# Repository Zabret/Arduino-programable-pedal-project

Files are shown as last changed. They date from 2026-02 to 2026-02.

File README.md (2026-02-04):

<p align="center">
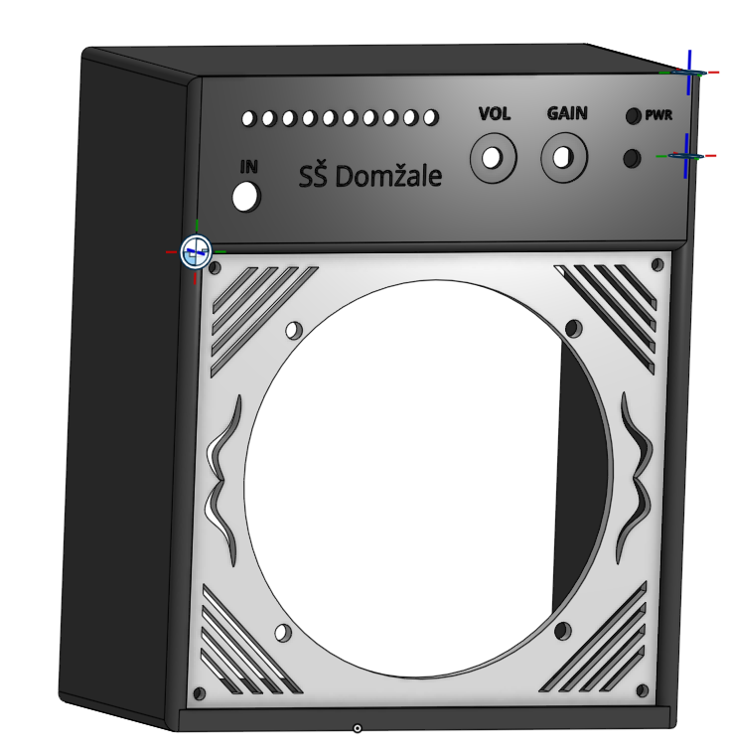
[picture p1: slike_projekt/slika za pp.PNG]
  
  &nbsp;&nbsp;&nbsp;&nbsp;
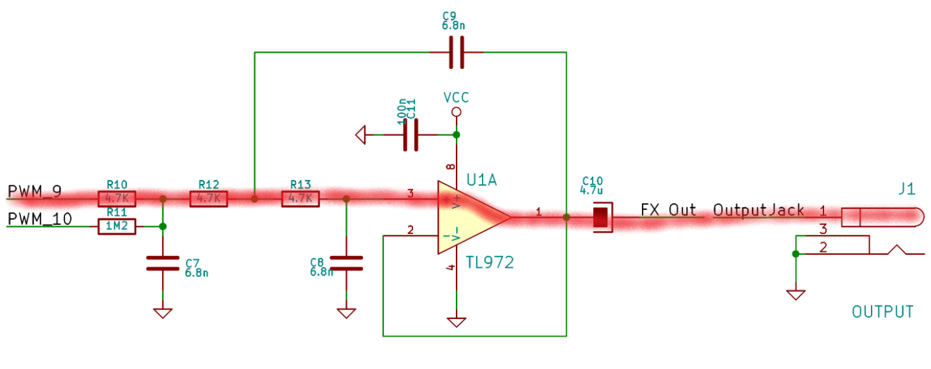
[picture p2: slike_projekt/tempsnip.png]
  
  &nbsp;&nbsp;&nbsp;&nbsp;
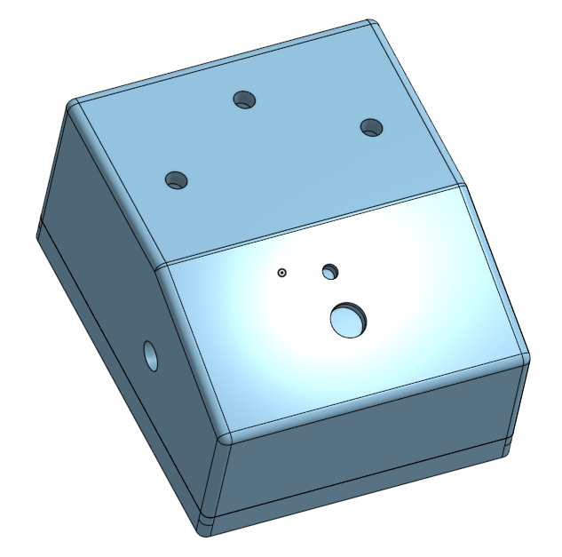
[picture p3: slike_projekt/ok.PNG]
  
</p>
<h1 align="center">Arduino-programable-pedal-project</h1>

A project insipred by Electrosmash arduino guitar pedal.
The report is about the construction process of an amplifier and a lo-fi programmable guitar pedal using an Arduino UNO microcontroller. The amplifier contains a 100W speaker powered by a 9V battery through a home-made printed circuit board. It also contains a VU-meter to monitor the sound signal strength. All components are built into the housing, which is made with the help of a 3D printer. The guitar pedal is also made from a homemade printed circuit board that amplifies the signal coming from the guitar and prepares it for the Arduino's analog-to-digital converter. The Arduino receives the digitized signal, processes it into the desired form of guitar effect (distortion, fuzz, bitcrusher,...) and sends it to the connected output unit or amplifier. The program that processes the signal is written in the C programming language.

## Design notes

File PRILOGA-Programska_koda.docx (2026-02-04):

# PRILOGA – programska koda

//Definiranje konstant in njihovih vhodnih pinov

#define LED 13

#define STOPALKA 12

#define STIKALO 2

#define GUMB_1 A5

#define GUMB_2 A4

//--------------------------------------------------------------------------------------------------------------------

//Nastavljanje pravilnih vrednosti izhodov PWM -Elecstrosmash(2017)

#define PWM_FREQ 0x00FF // Frekvenca 31,3kHz

#define PWM_MODE 0// Hitri način (1) ali način z fazno korekcijo (0)

#define PWM_QTY 2 // Nastavitev 2eh vzporednih izhodov

//--------------------------------------------------------------------------------------------------------------------

//Definiranje spremenljivk :

int input;

int stevec=0;

int efekt=0;

int pozicija=0;

byte ADC_low, ADC_high;

int glasnost=10000;

int max_f=6000;

int bitcrush=0;

//--------------------------------------------------------------------------------------------------------------------

void setup() {

// Določanje načina delovanja za vsako konstanto :

pinMode(STOPALKA, INPUT_PULLUP);

pinMode(STIKALO, INPUT_PULLUP);

pinMode(GUMB_1, INPUT_PULLUP);

pinMode(GUMB_2, INPUT_PULLUP);

pinMode(LED, OUTPUT);

//--------------------------------------------------------------------------------------------------------------------

// Nastavitev ADC (Analogno digitalnega pretvornika)-Elecstrosmash(2017)

ADMUX = 0x60;

ADCSRA = 0xe5;

ADCSRB = 0x07;

DIDR0 = 0x01;

//--------------------------------------------------------------------------------------------------------------------

// Nastavitev PWM (Pulzno širinske modulacije signalov):

TCCR1A = (((PWM_QTY - 1) << 5) | 0x80 | (PWM_MODE << 1));

TCCR1B = ((PWM_MODE << 3) | 0x11);

TIMSK1 = 0x20;

ICR1H = (PWM_FREQ >> 8);

ICR1L = (PWM_FREQ & 0xff);

DDRB |= ((PWM_QTY << 1) | 0x02);

//--------------------------------------------------------------------------------------------------------------------

//Razbere pozicijo stikala:

pozicija = digitalRead(STIKALO);

}

//--------------------------------------------------------------------------------------------------------------------

void loop() // ta del programa se vedno izvaja.

{

//Če je pedalo prižgano se prižge LED luč.

if (digitalRead(STOPALKA)) digitalWrite(LED, HIGH);

else digitalWrite(LED, LOW);

// Glede na pozicijo stikala se efekt spremeni.

if(digitalRead(STIKALO)!=pozicija)

{

pozicija = digitalRead(STIKALO); //Posodobi na novo vrednost.

efekt++;

if (efekt>3) efekt=0; //Če je efekt nastavljen na več kot vrednost 3, se nastavi na 0.

//Privzete vrednosti efektov:

glasnost=10000;

max_f=6000;

bitcrush=0;

}

}

//--------------------------------------------------------------------------------------------------------------------

ISR(TIMER1_CAPT_vect) {

// tukaj dobimo podatke iz ADC-ja

ADC_low = ADCL; // zapiše nižjo polovico bitov

ADC_high = ADCH; // zapiše višjo polovico bitov

input = ((ADC_high << 8) | ADC_low) + 0x8000; // ustvari podpisano 16 bitno število

//posodobi

stevec++;

if(stevec==100)

{

stevec=0;

//--------------------------------------------------------------------------------------------------------------------

//Če pritisnemo GUMB_2 se vrednosti izbranega efekta povečajo:

if (!digitalRead(GUMB_2)) {

if (glasnost<32768)glasnost=glasnost+10; //poveča glasnost

if (max_f<32768)max_f=max_f+25; //poveča fuzz

if (bitcrush<16)bitcrush=bitcrush+1; //poveča bitcrusher

digitalWrite(LED, LOW); //požmiga LED

}

//Če pritisnemo GUMB_1 se vrednosti izbranega efekta zmanjšajo:

if (!digitalRead(GUMB_1)) {

if (glasnost>0)glasnost=glasnost-10; //zmanjša glasnost

if (max_f>0)max_f=max_f-25; //zmanjša fuzz

if (bitcrush>0)bitcrush=bitcrush-1; //zmanjša bitcrusher

digitalWrite(LED, LOW); //požmiga LED

}

}

//--------------------------------------------------------------------------------------------------------------------

if (efekt==0)

{

//brez efekta.

}

else if(efekt==1) //glasnost

{

input = map(input, -32768, +32768,-glasnost, glasnost);

}

else if(efekt==2) //fuzz

{

if(input>max_f) input=32768;

else if(input<-max_f) input=-32768;

}

else if(efekt==3) //Bitcrusher

{

input = input<<bitcrush;

}

//izpiše PWM signal

OCR1AL = ((input + 0x8000) >> 8); // prevede nazaj v nadpisano število brez dvojiškega komplimenta

OCR1BL = input; // pošlje še nižji bit

}

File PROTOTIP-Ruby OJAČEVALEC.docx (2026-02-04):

# PROTOTIP – Ruby ojačevalec

## Kaj je Ruby ojačevalec ?

Je ojačevalec ki temelji na integriranem vezju LM386, ki ga je zasnoval Runoffgroove. Njegova naloga je ojačati signal ki pride iz kitare in ga predvajati skozi zvočnike.

## Osnutek načrta izdelave izdelka

Za izdelavo Ruby ojačevalca bi se zgledoval po sledeči shemi:

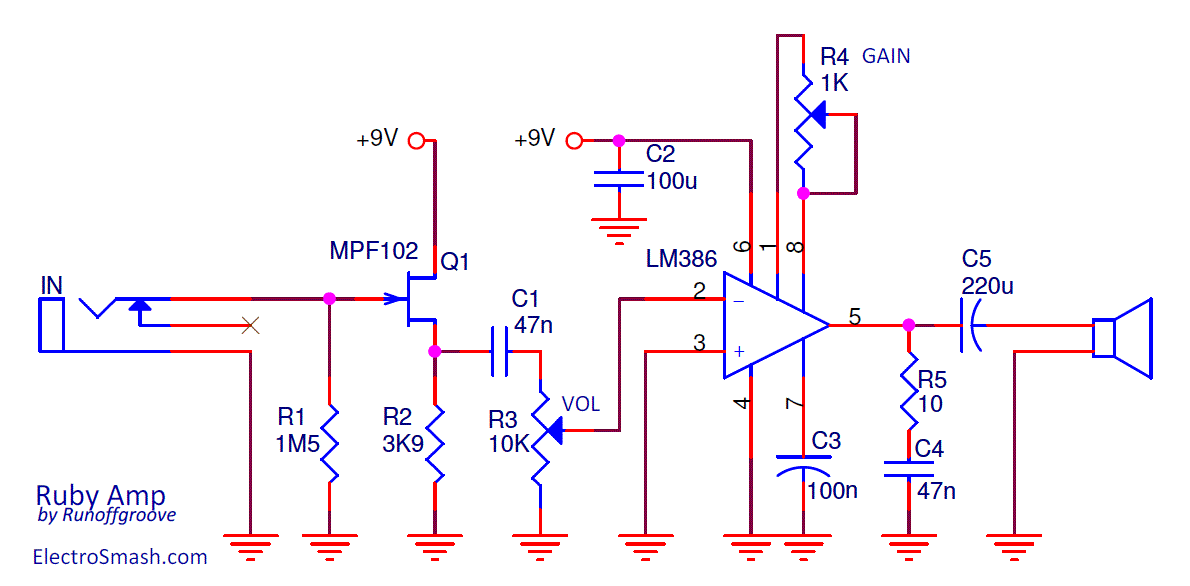
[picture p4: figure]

1W

Ojačevalec bi bil vezan na preprost 1W zvočnik, ki bi popolnoma zadoščal potrebam po glasnosti in kvaliteti. Navdih za ojačevalec sem dobil od izdelka na povezavi :
https://www.instructables.com/Portable-Ruby-Amp/

Ohišje ojačevalca bi ustvaril iz lesa in pomočjo domačega 3D-tiskalnika.

## Spisek komponent – Ruby ojačevalec

Reference | Št. kosov | Vrednosti | Opis
Kondenzatorji
C1, C4 | 2 | 47n
C2 | 1 | 100uf | electrolytic cap
C5 | 1 | 220uf | electrolytic cap
C3 | 1 | 100n
Uporniki
R5 | 1 | 10Ω
R2 | 1 | 3.9kΩ
R1 | 1 | 1.5MΩ
R6 | 1 | 4.7kΩ
R4 | 1 | 1kΩ
R3 | 1 | 10kΩ
Ostalo
MPF102 Tranzistor | 1
Potenciometer | 1 | 10KΩ
Potenciometer | 1 | 1KΩ
Stereo 6.35mm priključek | 1 | | ¼ stereo jack
9V priključek za baterijo | 1 | 9V
Baterija | 1 | 9V
Stikalo | 1 | | SPDT toogle switch
LED | 1 | 5mm
Prazna bakrena pcb ploščica -FR4 | 1 | | 100mm*70mm
zvočnik | 1 | 1W
LM386IC | 1

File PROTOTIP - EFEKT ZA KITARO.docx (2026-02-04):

# PROTOTIP – KITARSKI EFEKT

## Kaj so kitarski efekti?

Kitarski efekti so elektronske naprave, ki spreminjajo ton, njegovo višino, ali zvok električne kitare. Poleg električne kitare so te efekti vgrajeni tudi v električnih klavirjih in bass kitarah.

## Osnutek načrta izdelave izdelka

Za izdelavo kitarskega efekta bi se zgledoval po shemi pedalshieldUNO (https://www.electrosmash.com/pedalshield-uno) avtorja electroSmash, ki temelji na implementaciji arduino-UNO mikrokontrolerja skupaj s posebnim tiskanim vezjem ki omogoča prenos in alteracijo signala električne kitare skozi arduino do ojačevalca.

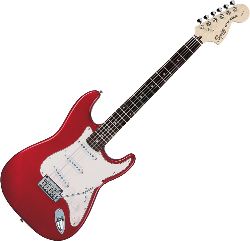
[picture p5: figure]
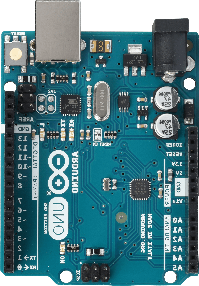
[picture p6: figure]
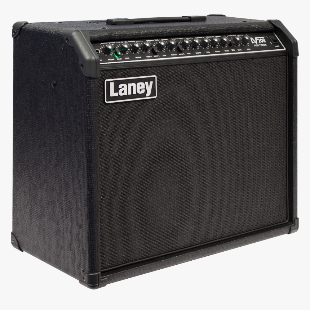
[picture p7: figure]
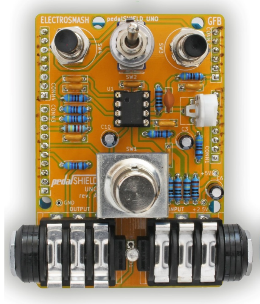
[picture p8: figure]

signal

signal

vmesnik

arduino

Glavna komponenta izdelka bo vmesnik, ki bo omogočal arduinu dostop do signala kitare, hkrati pa vseboval tudi stikala za sam efekt.

Vmesnik bi zgradil na tiskanem vezju katerega bi ustvaril s pomočjo jedkanja ali laserskega graviranja bakrene ploščice namenjene gradnji vezij, na katero bi potem za spajkal potrebne elemente.
Ohišje efekta bi natančno narisal v CAD programu in ustvaril s pomočjo domačega 3-D tiskalnika.

Zadnji korak pri izdelavi izdelka je sama koda, ki bi omogočala pretvorbo oziroma spremembo signala za zaželen efekt. Program bi napisal v programskem jeziku C++, po zgledu Electrosmash zbirke digitalnih efektov.

Pri izdelavi vezja bi se zgledoval po sledeči shemi :

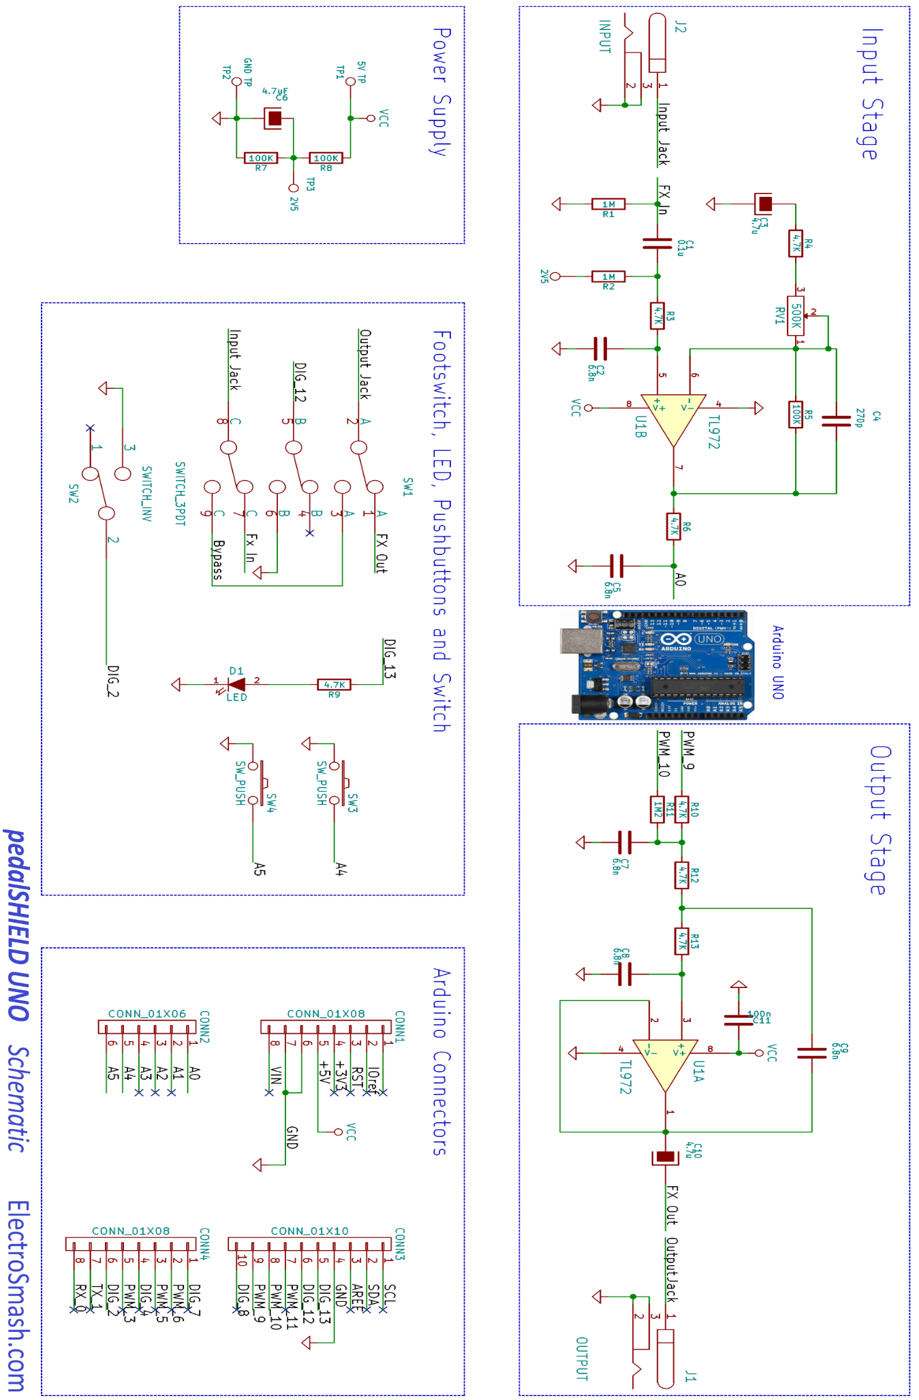
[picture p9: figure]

## Spisek komponent -efekt

Reference | Št. kosov | Vrednosti | Opis | Mauser reference
Kondenzatorji
C5,C2, C7, C8, C9 | 5 | 6.8n | ceramic cap | SR211C682MARTR1
C3, C6, C10 | 3 | 4.7u | electrolytic cap | ECE-A1EKA4R7
C1, C11 | 2 | 100n | ceramic cap | SR211C104KARTR1
C4 | 1 | 270p | ceramic cap | D271K20Y5PH63L6R

Uporniki
R12,R13, R10, R9, R6, R4, R3 | 7 | 4.7K | Resistor, 1%,1/4W | MFR-25FRF52-4K7
R5, R7, R8, | 3 | 100K | Resistor, 1%,1/4W | MFR-25FRF52-100K
R1, R2 | 2 | 1M | Resistor, 1%,1/4W | MFR-25FRF52-1M
R11 | 1 | 1M2 | Resistor, 1%,1/4W | MFR-25FRF52-1M2

Ostalo
RV1 | 1 | 500K | resistor trimmer | 3319W-1-504
D1 | 1 | Led 3mm blue | blue led 3mm | SSL-LX3044USBC
U1 | 1 | TL972 pdip-8 | op-amp rail-to-rail | 595-TL972IP
IC Socket | 1 | dip 8 socket | socket dor dip8 | 1-2199298-2
SW1 | 1 | 3DPT footswitch | 3PDT footswitch | 107-SF17020F-32-21RL
SW2 | 1 | Toggle switch | SPDT toogle switch | 612-100-A1111
SW3, SW4 | 2 | Pushbutton | off-on pushbutton | 103-1013-EVX
Conn1,2,3,4 | 1 | 40 pin headers | 2.54 pitch pin header | 710-61304011121
J1, J2 | 2 | 1/4 Jack audio | stereo 6.35mm jack | NMJ6HCD2
Prazna bakrena pcb ploščica -FR4 | 1

*Bakreno pcb ploščico bi po potrebi lahko zamenjal tudi z protoboardom.

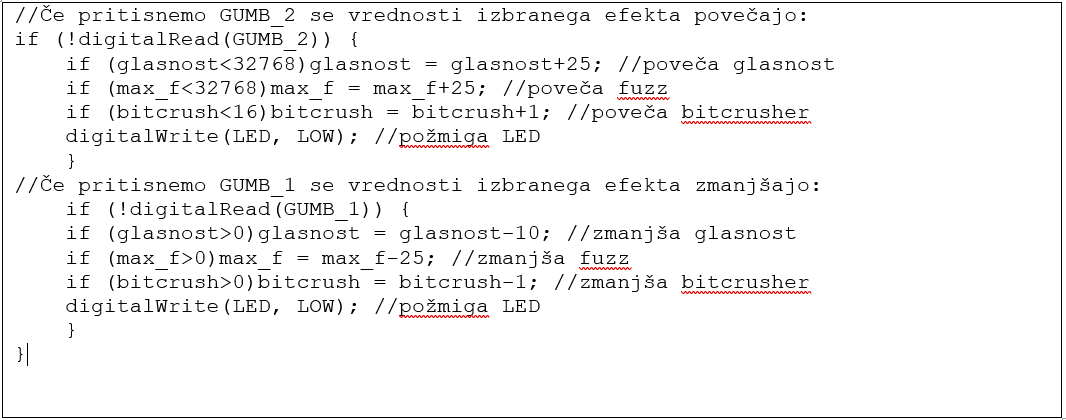
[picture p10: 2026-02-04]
slike_projekt/p.PNG

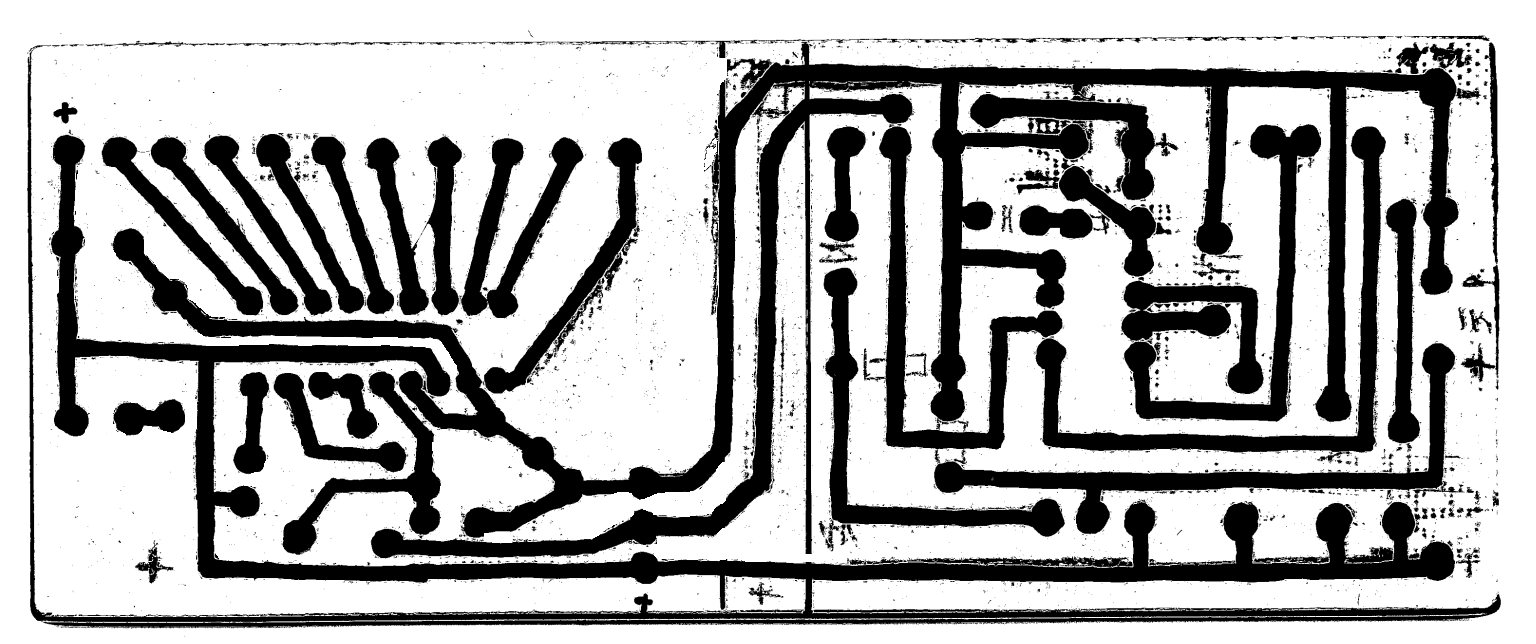
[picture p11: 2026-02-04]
slike sheme/shema ojacevalec.PNG

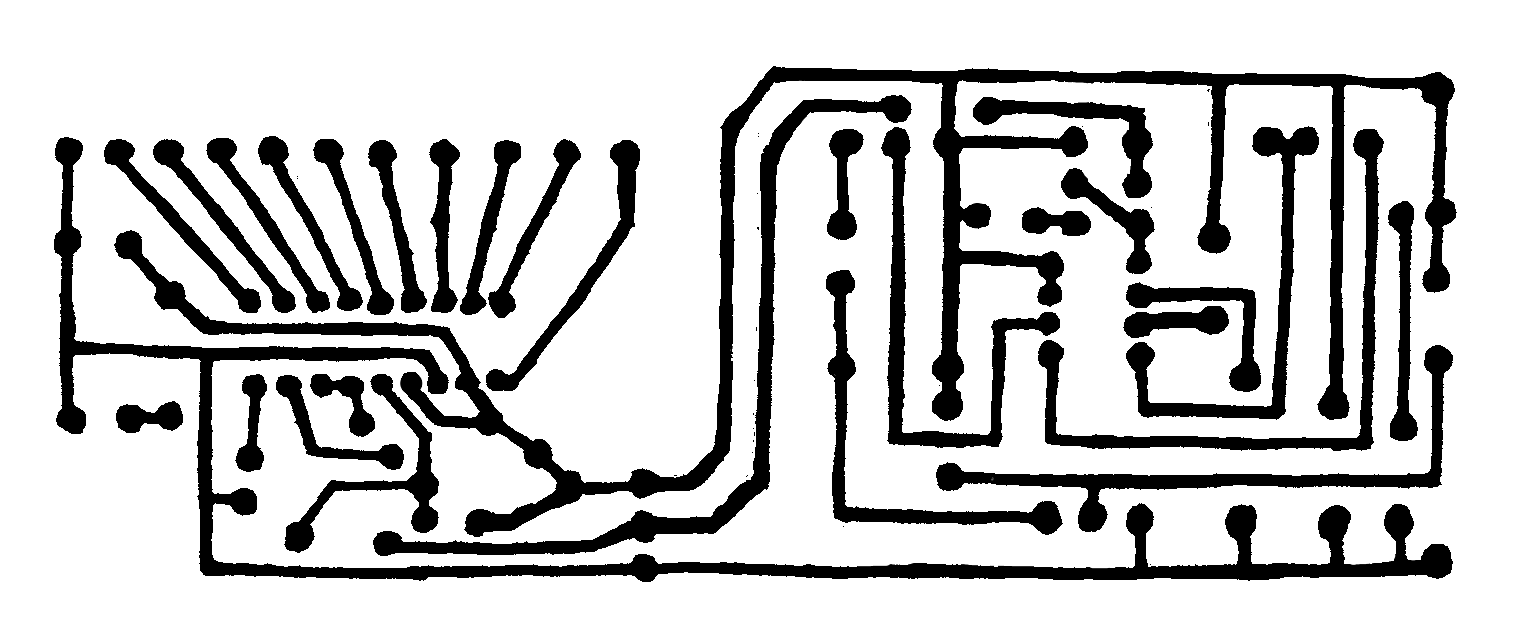
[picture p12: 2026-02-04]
slike sheme/shema ojacevalec pt2.png

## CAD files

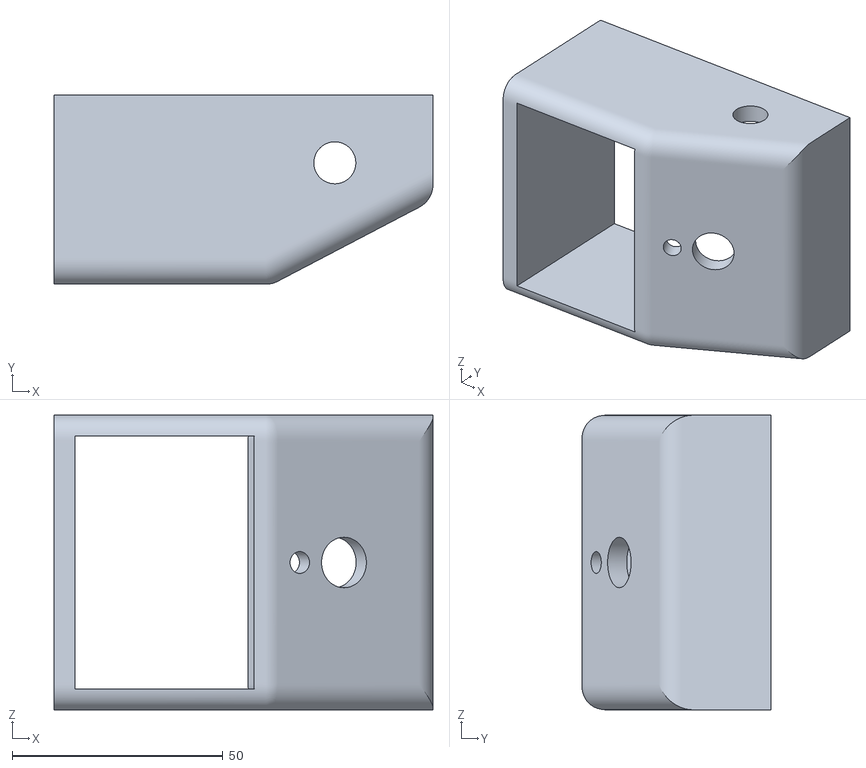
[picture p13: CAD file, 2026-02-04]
3D_datotekeGCODE/okvir_za_pedal.stl
90.0 x 45.0 x 70.0

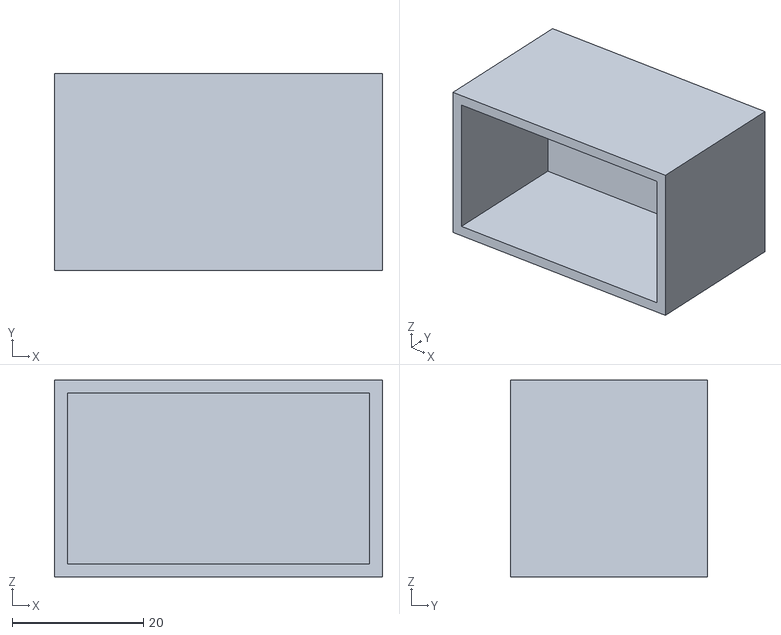
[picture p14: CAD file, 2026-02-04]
3D_datotekeGCODE/skatlica.stl
50.0 x 30.0 x 30.0

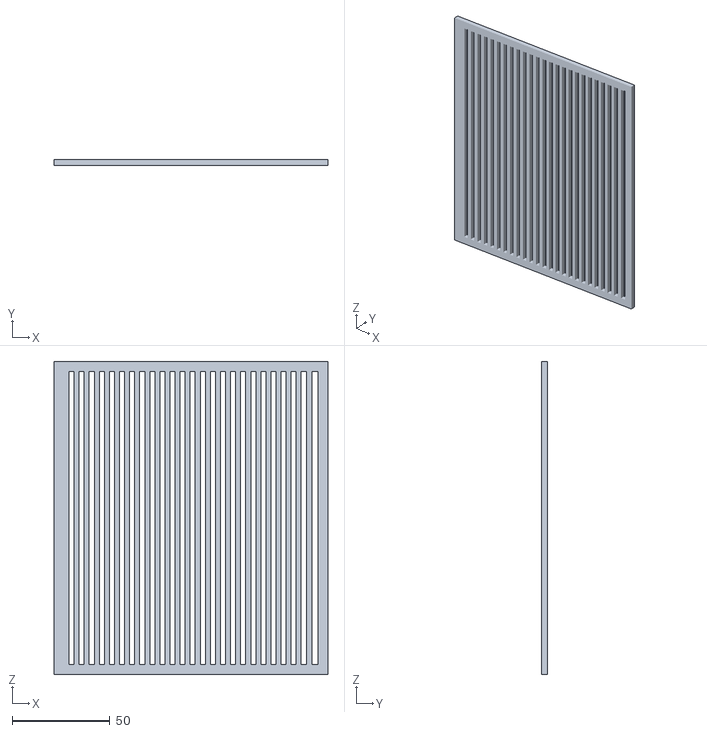
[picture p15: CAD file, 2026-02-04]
3D_datotekeGCODE/resetka1.stl
140.0 x 3.00 x 160.2

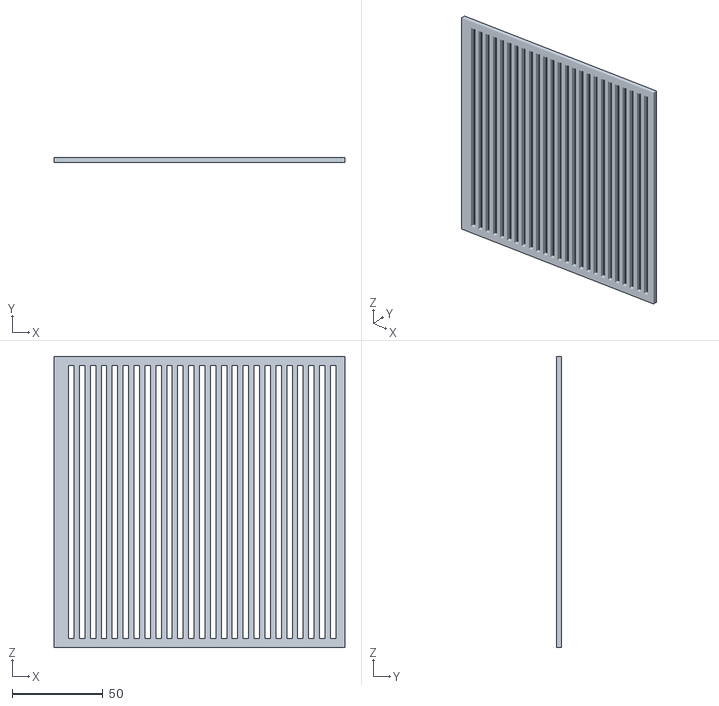
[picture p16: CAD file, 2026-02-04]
3D_datotekeGCODE/resetka.stl
160.0 x 3.00 x 160.2

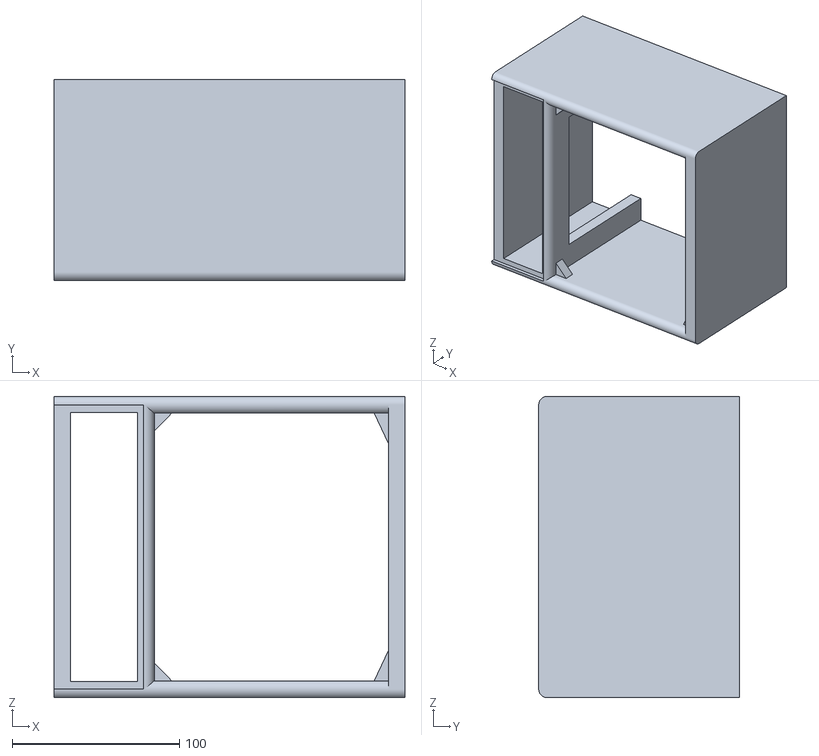
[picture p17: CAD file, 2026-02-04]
3D_datotekeGCODE/ohisje_ojacevalca1.stl
210.0 x 120.0 x 180.2

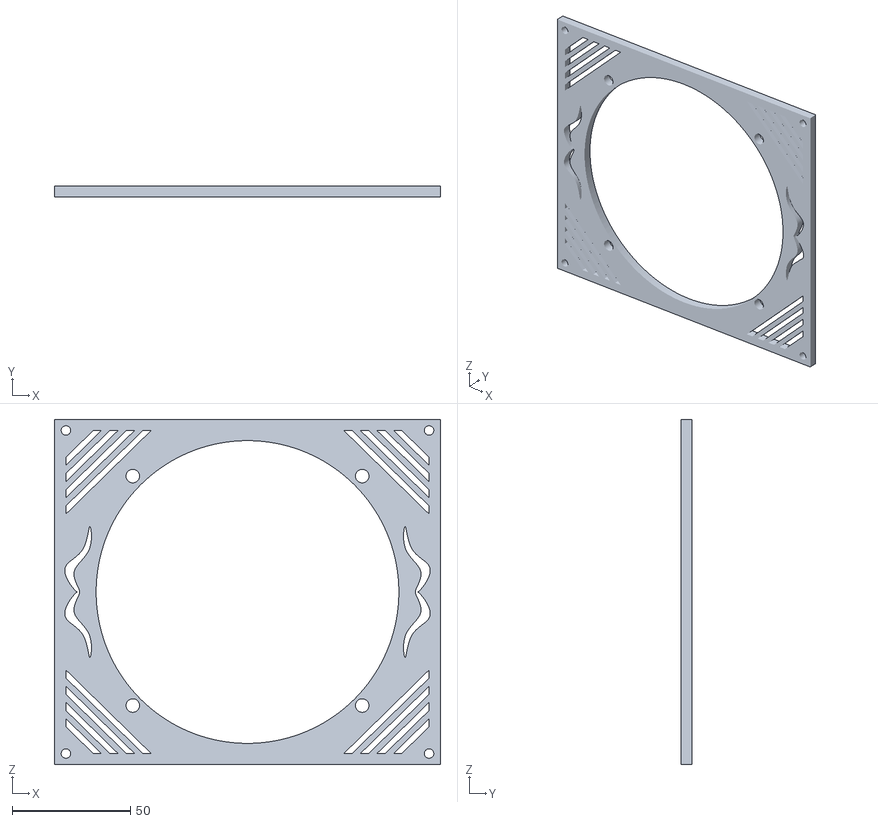
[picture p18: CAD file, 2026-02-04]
3D_datotekeGCODE/posodoblena_resetka.stl
163.2 x 4.50 x 146.0

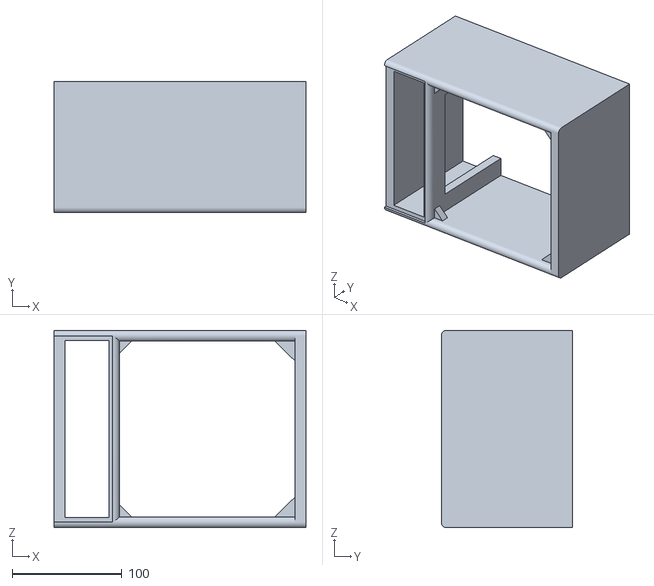
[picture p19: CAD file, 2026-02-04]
3D_datotekeGCODE/ohisje_ojacevalca.stl
230.0 x 120.0 x 180.2

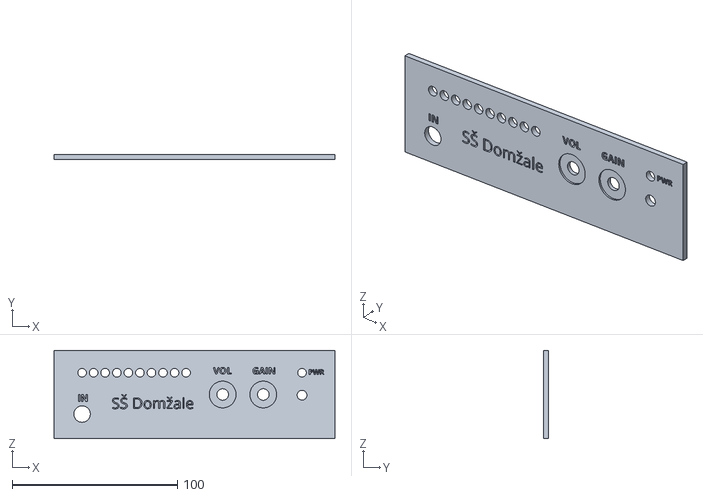
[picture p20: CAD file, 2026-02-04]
3D_datotekeGCODE/celna_plosca.stl
170.2 x 3.00 x 53.5

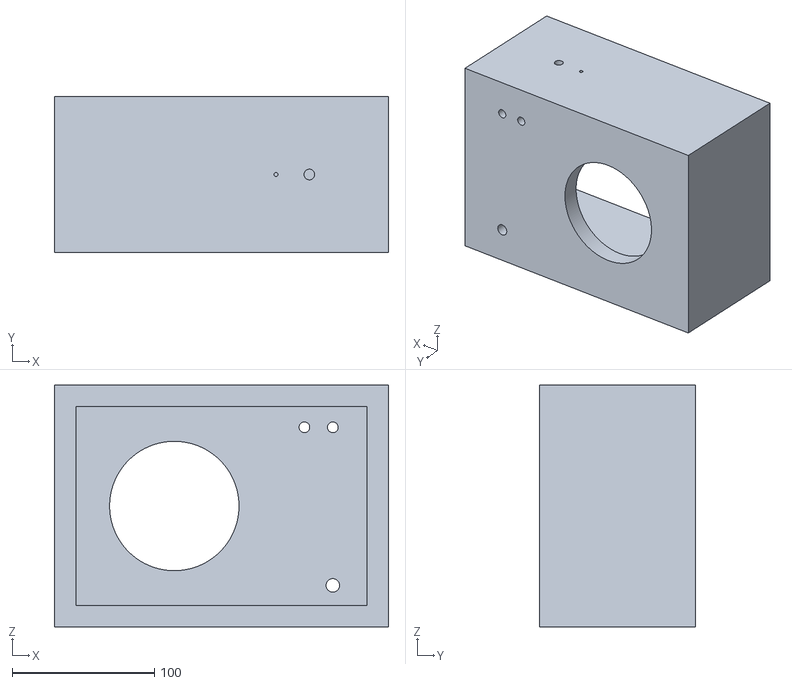
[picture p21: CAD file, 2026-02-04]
3D_datotekeGCODE/Ojačevalec.stl
235.0 x 110.0 x 170.0

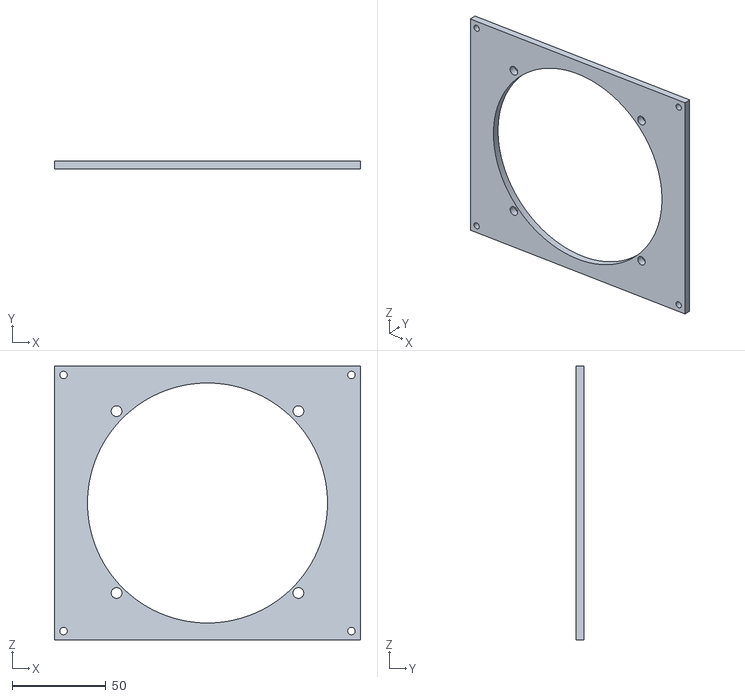
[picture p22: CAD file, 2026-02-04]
3D_datotekeGCODE/resetkanova.stl
163.2 x 4.50 x 146.0

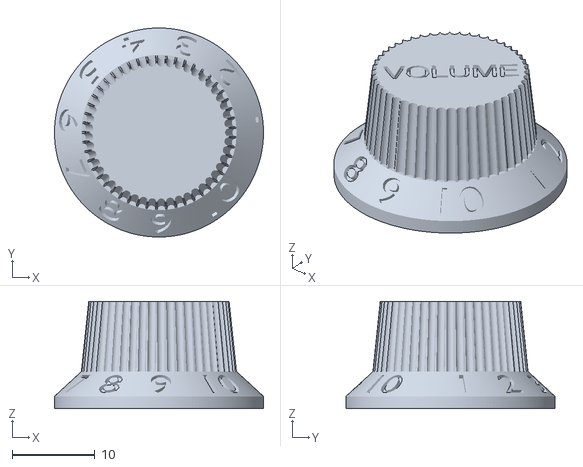
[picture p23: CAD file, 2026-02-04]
3D_datotekeGCODE/knob_right_volume.stl
25.3 x 25.3 x 13.0

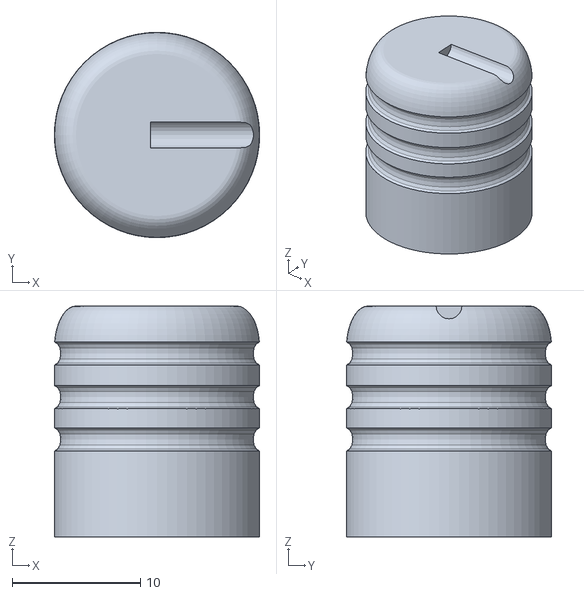
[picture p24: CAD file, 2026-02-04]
3D_datotekeGCODE/ring_Guitar_Amp_Knob.stl
16.0 x 16.0 x 18.0

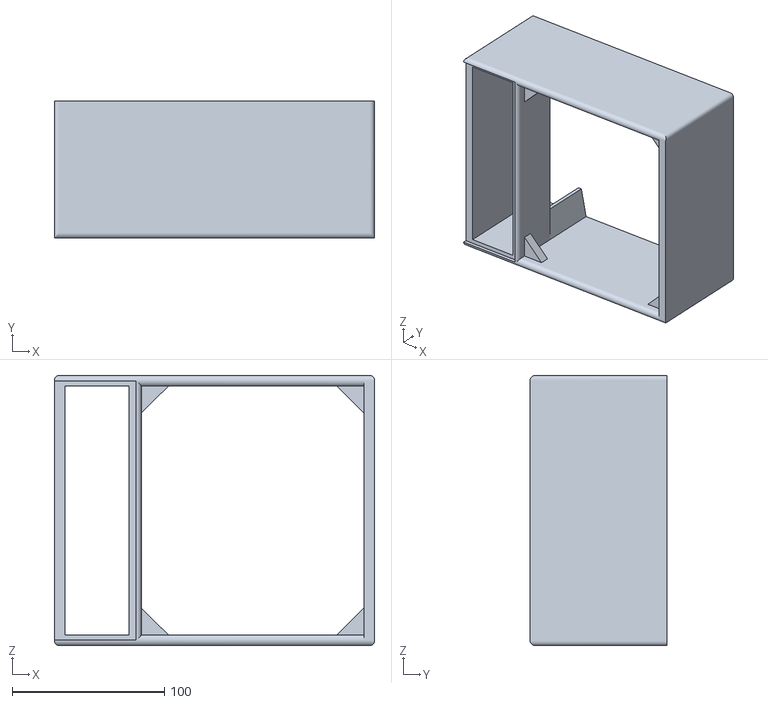
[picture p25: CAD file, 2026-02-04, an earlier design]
3D_datotekeGCODE/ohisje_ojacevalca (3).stl
210.0 x 90.0 x 177.2

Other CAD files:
3D_datotekeGCODE/Čelna_Plošča.stl

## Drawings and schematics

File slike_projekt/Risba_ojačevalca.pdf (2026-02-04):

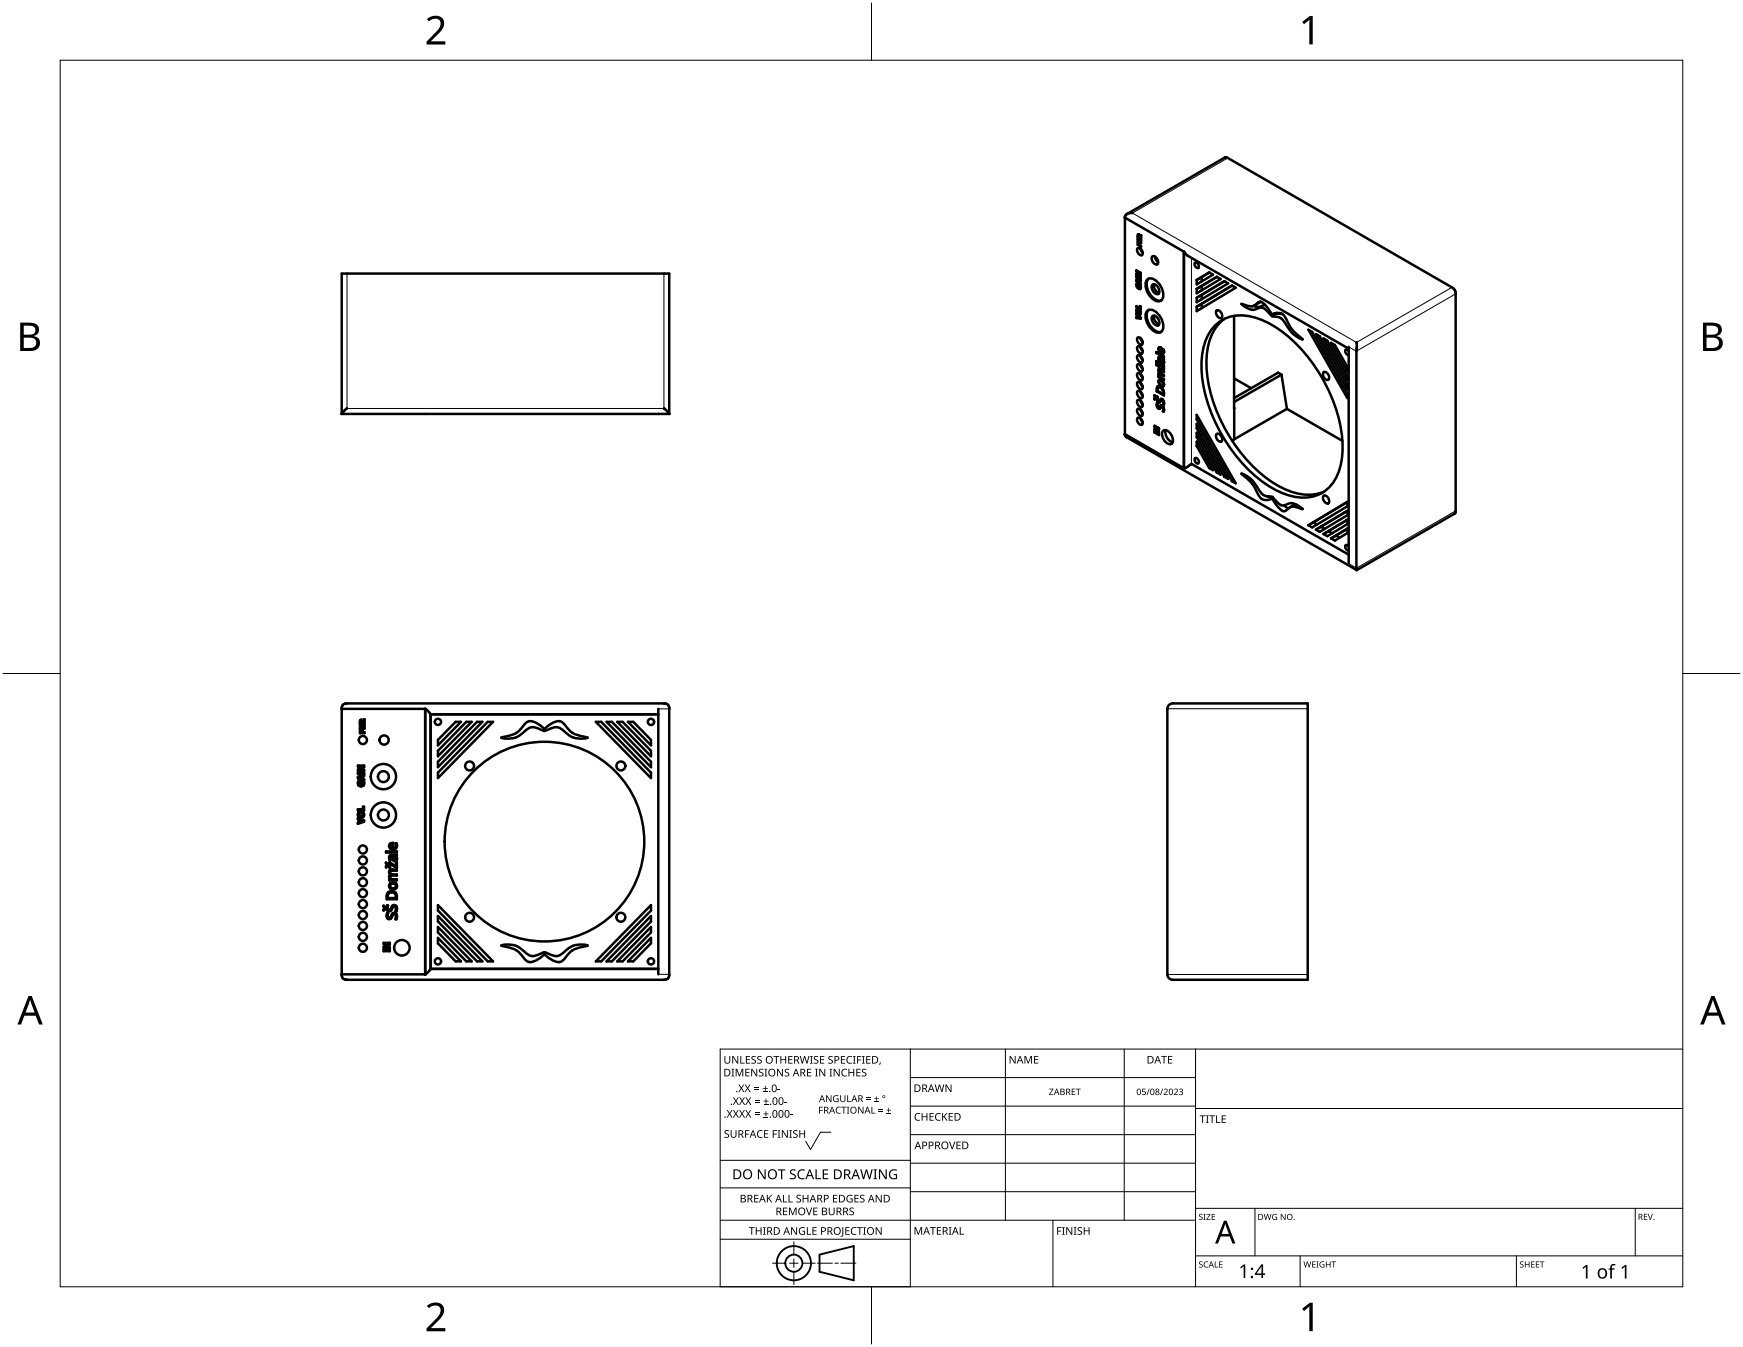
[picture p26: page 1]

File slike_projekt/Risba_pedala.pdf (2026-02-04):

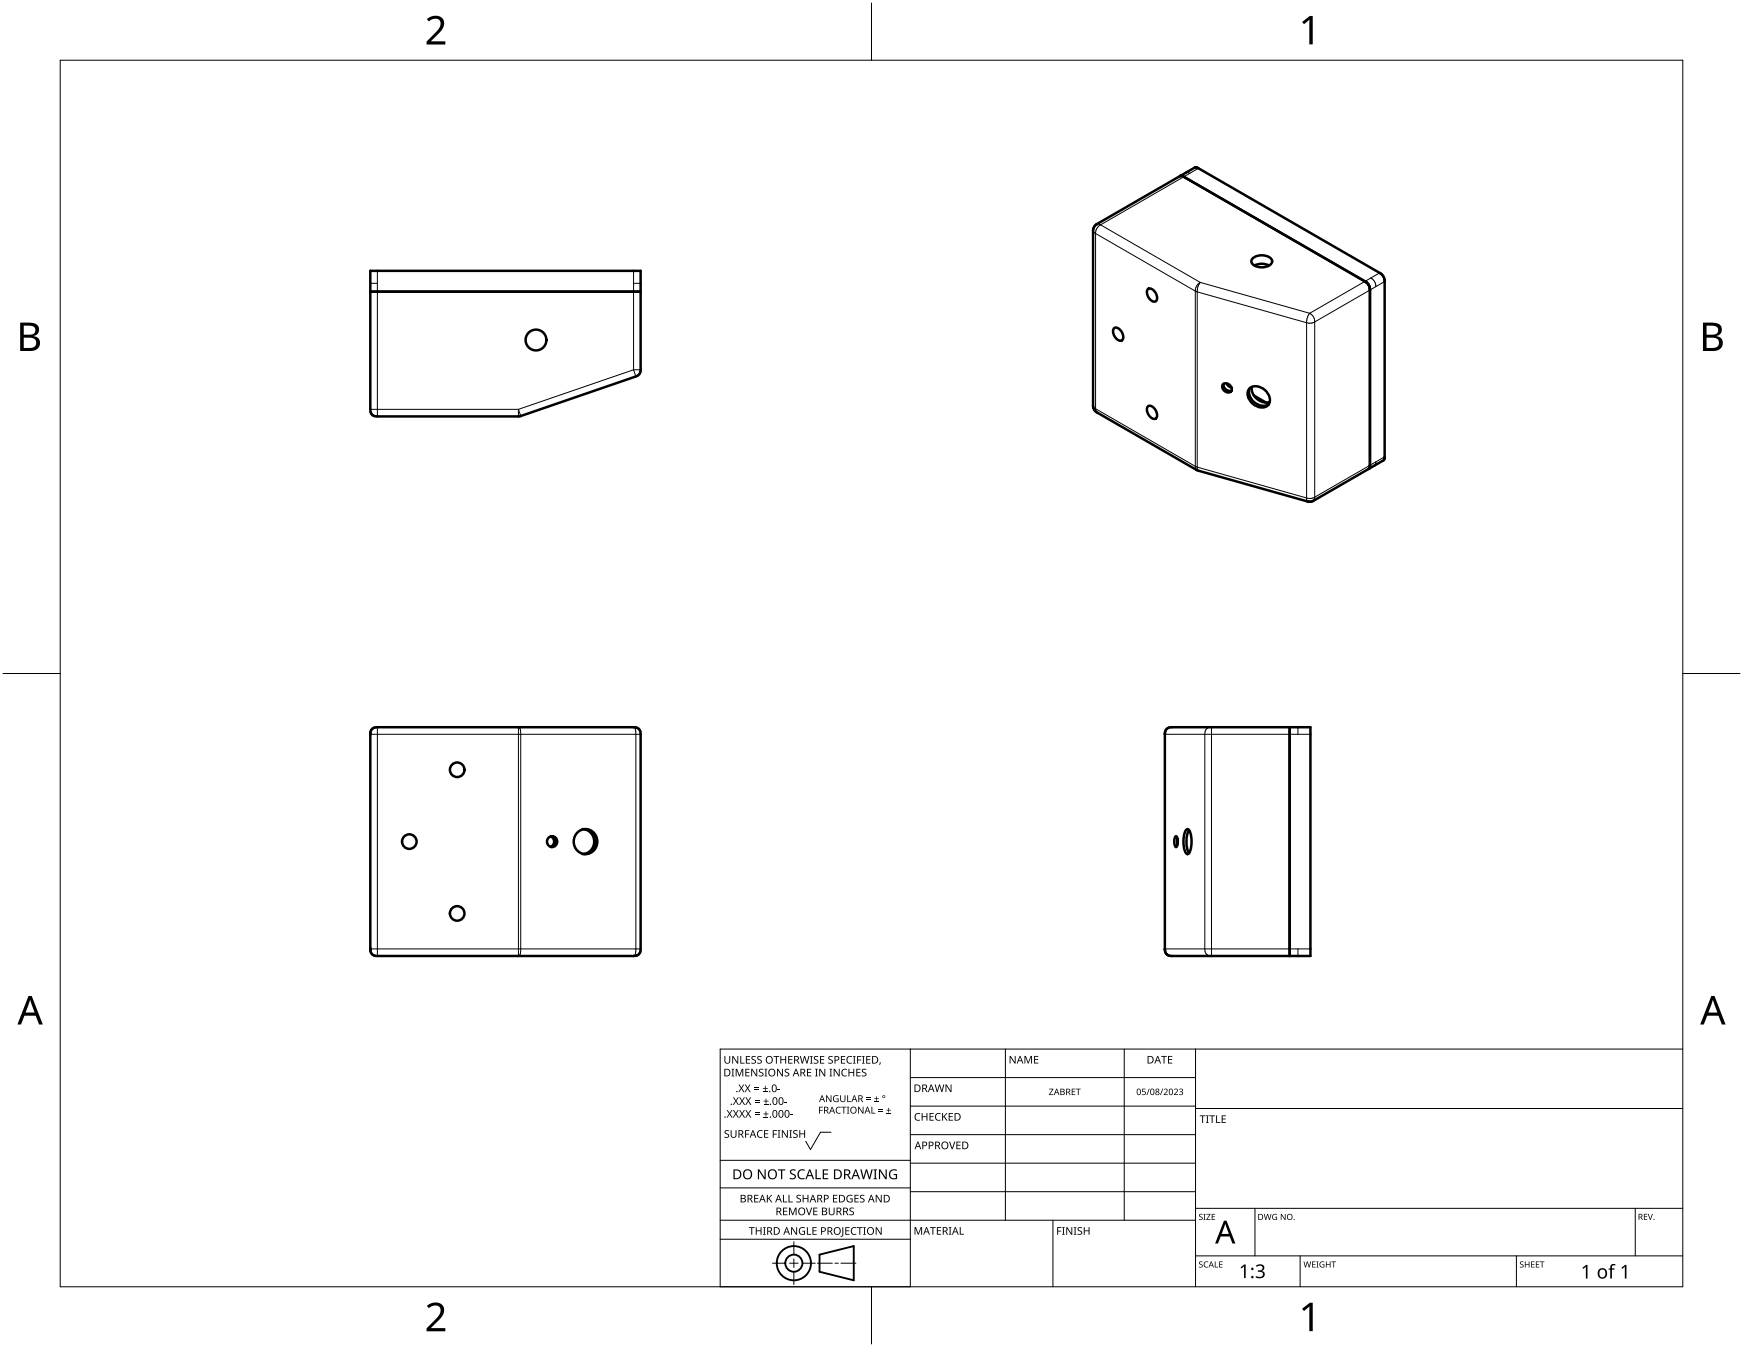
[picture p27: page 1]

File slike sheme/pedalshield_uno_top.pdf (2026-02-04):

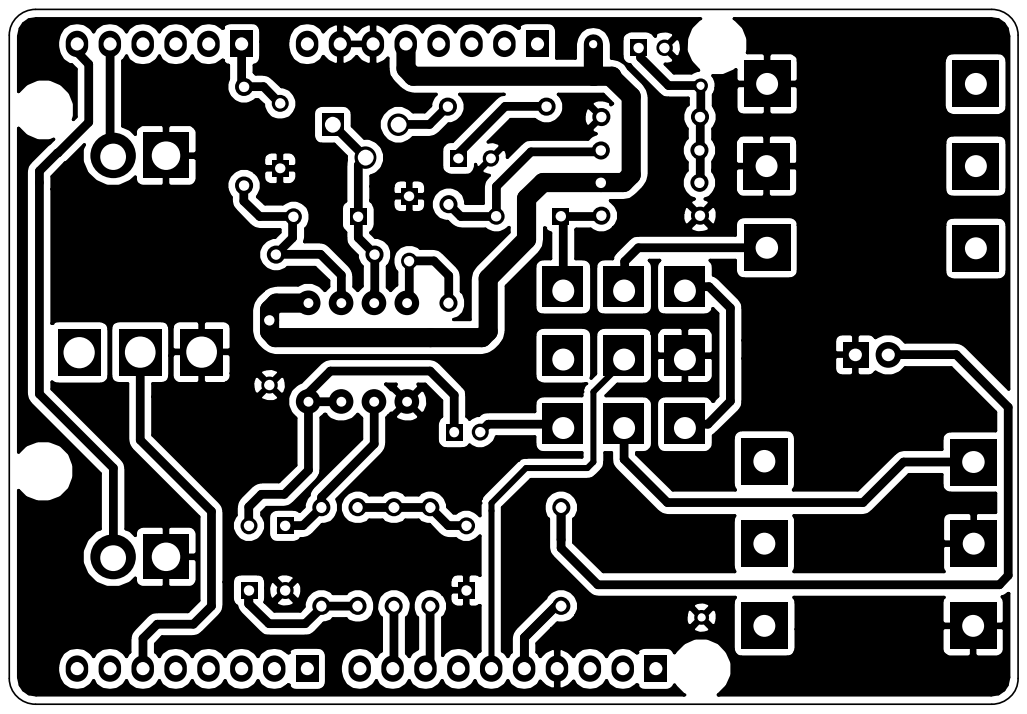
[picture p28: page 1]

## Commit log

2026-02-04 Add schematic image to README
    Added an image for the schematic of the amplifier.
2026-02-04 Fix image filename case in README
    Updated image filename extension from 'ok.png' to 'ok.PNG'.
